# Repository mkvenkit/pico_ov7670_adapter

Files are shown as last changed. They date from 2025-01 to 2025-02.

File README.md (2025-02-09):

# pico_ov7670_adapter

An adapter PCB for using Pico 2W with an OV7670 camera module.

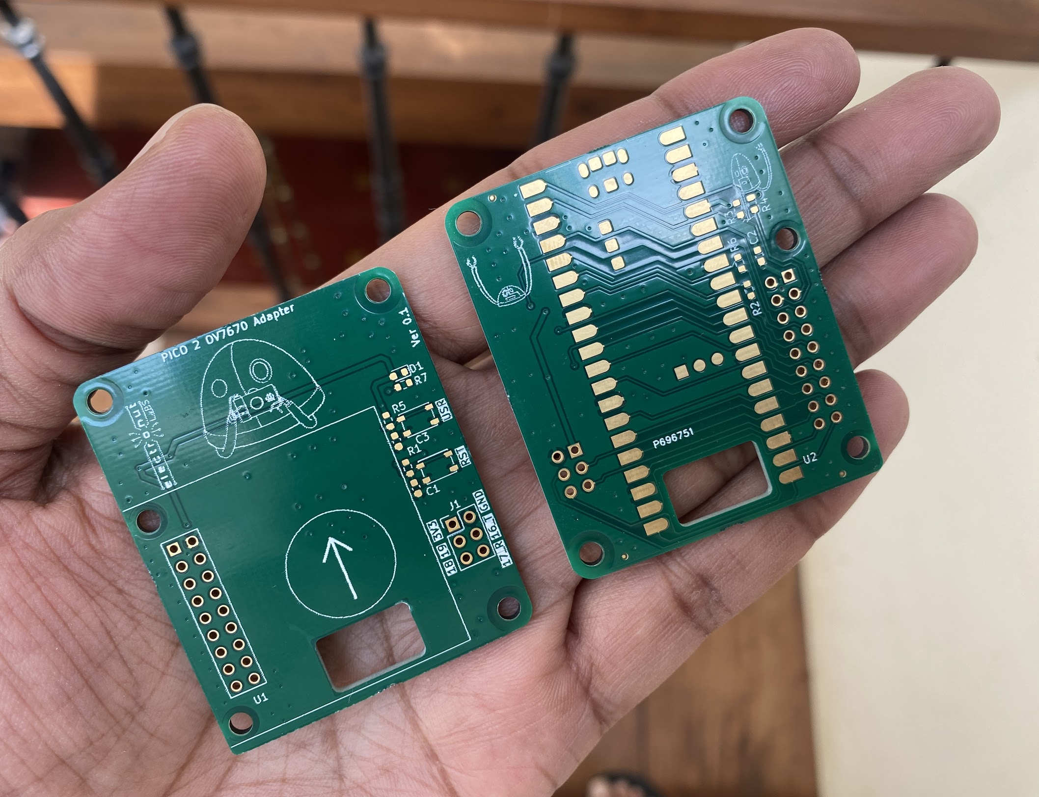
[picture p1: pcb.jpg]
pcb


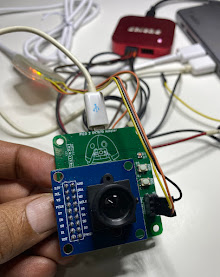
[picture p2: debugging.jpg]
debugging


# License

<p xmlns:cc="http://creativecommons.org/ns#" xmlns:dct="http://purl.org/dc/terms/"><a property="dct:title" rel="cc:attributionURL" href="http://electronut.in">Pico 2 OV7670 Adapter PCB</a> by <a rel="cc:attributionURL dct:creator" property="cc:attributionName" href="http://electronut.in">Mahesh Venkitachalam</a> is licensed under <a href="https://creativecommons.org/licenses/by/4.0/?ref=chooser-v1" target="_blank" rel="license noopener noreferrer" style="display:inline-block;">CC BY 4.0</a></p>

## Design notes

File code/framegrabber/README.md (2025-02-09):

# Frame Grabber for Pico 2 OV7670 Adapter

This is a frame grabber for capturing QVGA (320 x 420) RGB56 images and sending them over UART. The serial data is parsed by a Python program on the computer and a PNG RGB image created.

### UART Pins

```
UART_TX_PIN GP16
UART_RX_PIN GP17
```

## Current Status 

Output is garbled.

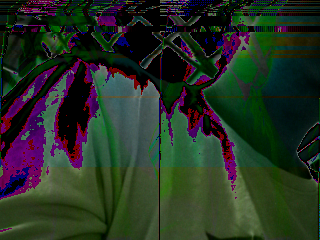
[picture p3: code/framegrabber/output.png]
output


Output with lenscap:

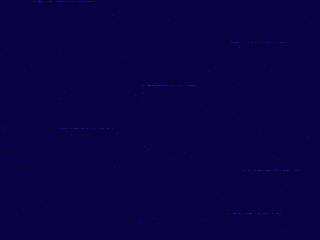
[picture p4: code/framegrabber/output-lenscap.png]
output with lenscap


## OV7670 Setup

The OV7670 registers are set to QVGA RGB565. I2C is verified to be working. Changing reg values is changing signal output.

### Signals from Logic Analyzer

The signals from OV7670 are consistent with QVGA (320 x 240) RGB565 - 2 PCLK pulses per pixel.

I am supplying XCLK at 15 MHz. Hence PCLK is at about 7.5 MHz.

**VSYNC**

Here's VSYNC. It's the same for VGA, QVGA, etc. Timing is correct.

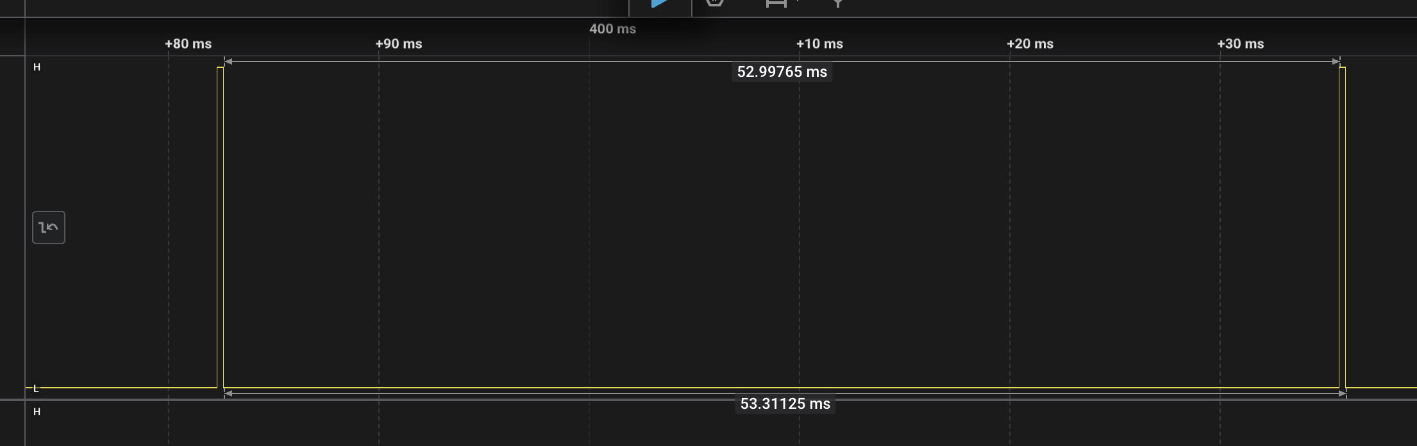
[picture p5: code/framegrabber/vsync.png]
vysnc


**HREF**

Here's HREF. 

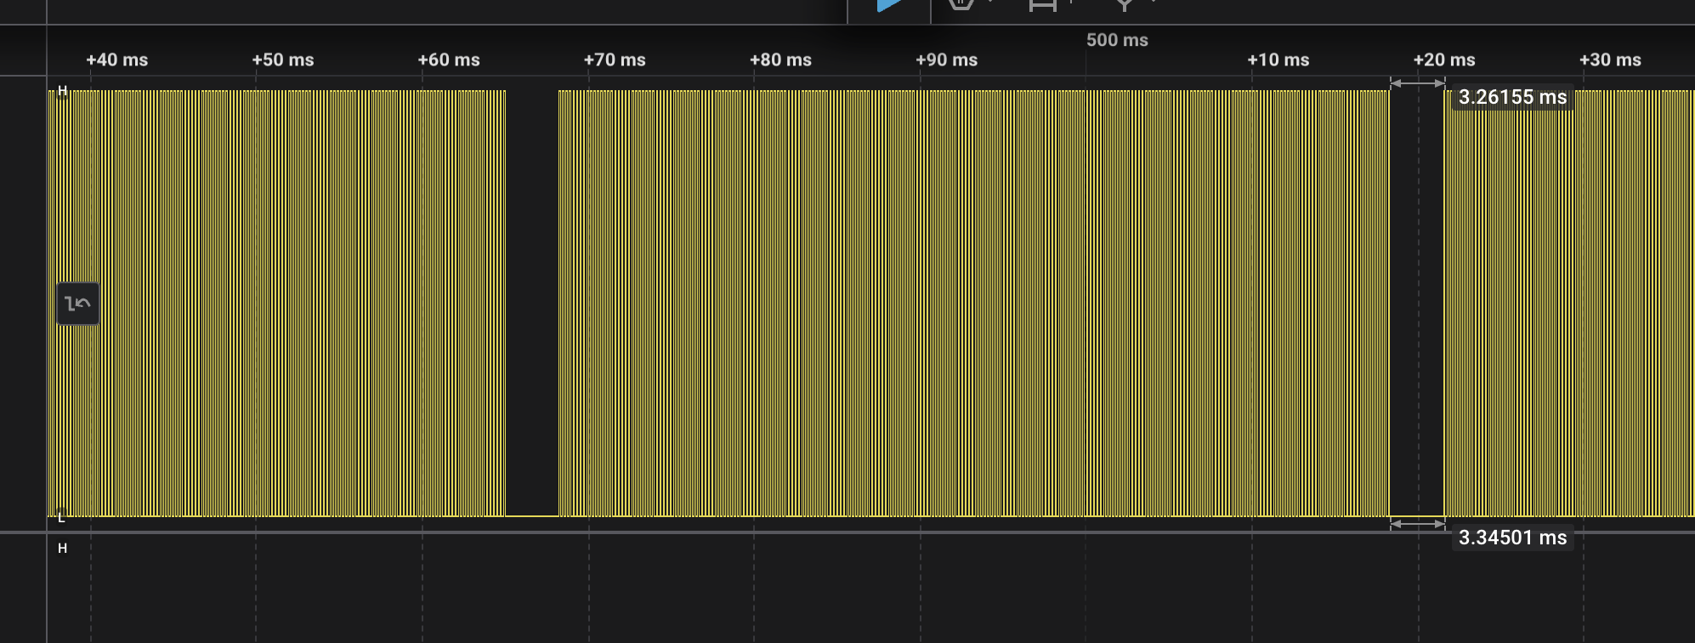
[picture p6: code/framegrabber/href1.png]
href1


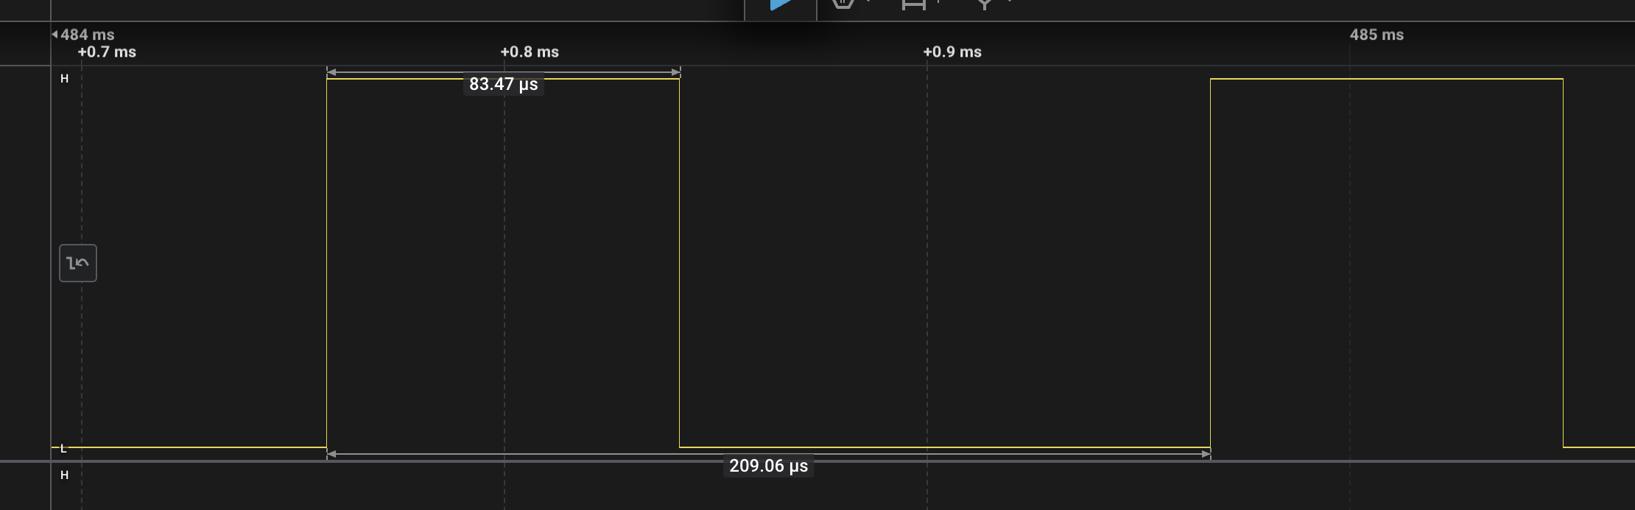
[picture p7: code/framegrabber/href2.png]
href2


From the above, 50.17 ms/(209.07 us) = 239.96 - ie, 240 is the number of rows, or height of the image. 

**PCLK**

Here's PCLK and HREF together.

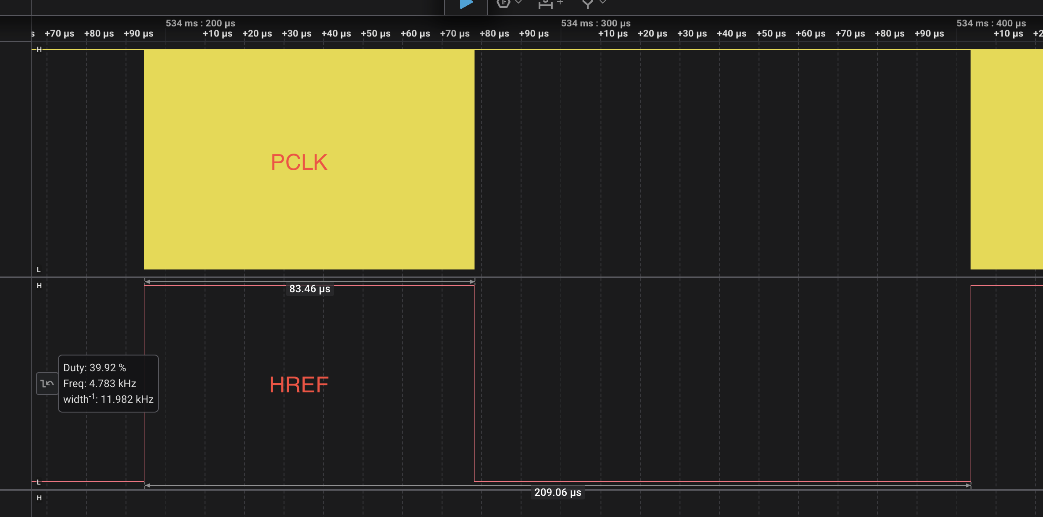
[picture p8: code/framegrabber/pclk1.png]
pclk1


Here's PCLK by itself.

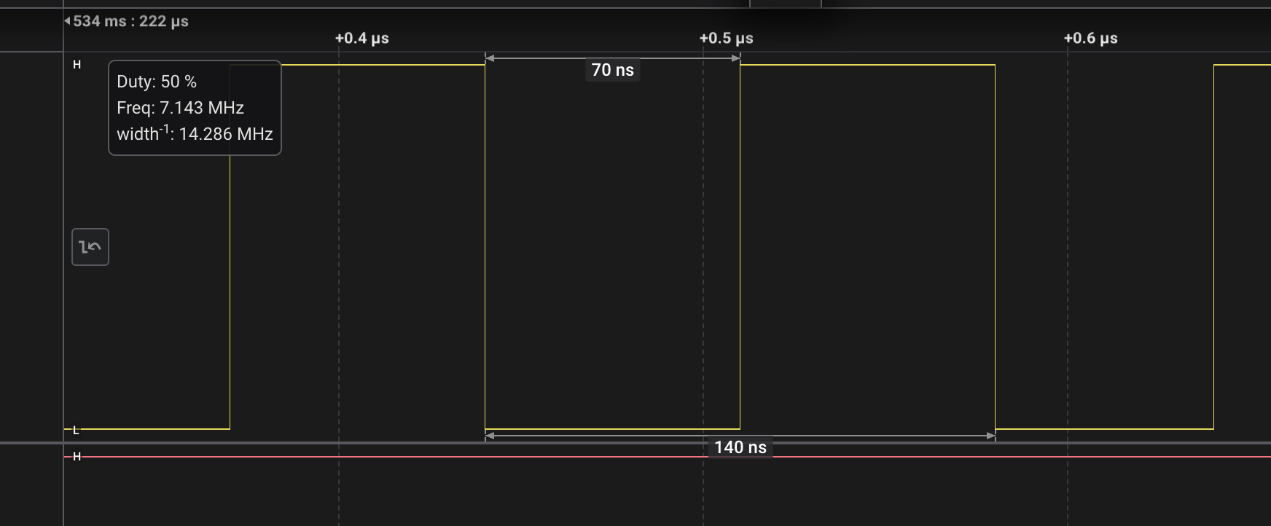
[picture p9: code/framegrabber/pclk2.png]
pclk2


From the above, 83.46 us/ 130 ns = 642. So 640 is the image width. At 2 x PCLKs per pixels, it's consistent with 2 * 320 = 640.

## Data Pins

On the PCBs, OV7670 D7..D0 are connected to GP6...GP13.

So,keeping GP6 as BASE pin in PIO, means that our data byte will be flipped in bits. This is corrected per byte before transmitting via UART.

## PIO

The PIO below does the following:

1. Read width (2 * 320 - 1 = 639) from TX FIFO.
2. Read OSR value into X register.
3. Wait for HREF to go high.
4. Wait for PCLK to go high.
5. Read in 8 pins GP6-GP13 to ISR. SM is set to auto-push from ISR to RX FIFO.
6. Loop till x-- is 0 (post-decr, hence N-1)

```
.program ov7670_qvga_565

    pull block    ; wait for width from OSR which comes from TX FIFO via auto-push
    wait 1 pin 2  ; Wait for VSYNC high (GP2 - Start of new frame)
    wait 0 pin 2  ; Wait for VSYNC low

.wrap_target
    mov x, OSR    ; move from OSR to X
    wait 1 pin 3  ; Wait for HREF high (GP3 - Row start)

pixel_loop:
    wait 1 pin 4  ; Wait for PCLK rising edge (GP4 - Pixel clock)
    in pins, 8    ; Read 8-bit pixel data from GP0-GP7
    wait 0 pin 4  ; Wait for PCLK falling edge
    jmp x-- pixel_loop  ; Continue while X not 0

    wait 0 pin 3  ; Wait for HREF low 
.wrap
```

## DMA 

The DMA is set up as follows:

1. 32 bit data transfer.
2. src is RX FIFO.
3. dst is uint8_t* buffer.
4. Data length is 2 * 320 * 240 / 4 bytes

I have tested the PIO + DMA by removing OV7670, setting D7-D0 using wires to the bit pattern 0xCB and it was received via UART on the PC correctly.

## Data Format

On PCLK, 8 bits GP6-GP13 are right-shifted into the 32-bit ISR, and after 4 PCLKs, ISR is auto-pushed to the RX FIFO which looks like:

```
|GP13...GP6|GP13...GP6|GP13...GP6|GP13...GP6|
```

This is copied by DMA to uint8_t* buffer and the write address incremented.

So the bytes end up in uint8_t* buffer as:

```
[0] GP13...GP6
[1] GP13...GP6
[2] GP13...GP6
[3] GP13...GP6
```

Before UART transmission, each byte is reversed - so we have:

```
[0] GP6...GP13
[1] GP6...GP13
[2] GP6...GP13
[3] GP6...GP13
```

Which is same as:

```
[0] D7...D0
[1] D7...D0
[2] D7...D0
[3] D7...D0
```

Which is correct. [0] and [1] are the RGB565 values for a pixel split across two bytes.

## Development Plan 

1. [+] Send a PWM to XCLK and check href, vsync, pclk signals.
2. [+] Hook up I2C and set output to 320 x 240 - check signals for correctness
3. [+] Write PIO code.
3. [+] Set up DMA to transfer to buffer.
4. [+] UART code to send buffer.
5. [+] Python code on PC to read from serial and display image data 

## Equivalent PIO of Sandeep's code

https://github.com/ArmDeveloperEcosystem/hm01b0-library-for-pico/blob/main/src/hm01b0.c#L149

```
.program camera_capture
    pull        block      ; Pull OSR value into PIO
    wait 0 pin vsync_pin  ; Wait for VSYNC to go low
    wait 1 pin vsync_pin  ; Wait for VSYNC to go high
    set y, num_border_px-1

border_y_loop:
    wait 1 pin hsync_pin  ; Wait for HSYNC to go high
    wait 0 pin hsync_pin  ; Wait for HSYNC to go low
    jmp  y--, border_y_loop

.wrap_target
    mov x, osr            ; Load OSR into X register
frame_loop:
    wait 1 pin hsync_pin  ; Wait for HSYNC to go high
    set y, num_border_px * num_pclk_per_px - 1

border_x_loop:
    wait 1 pin pclk_pin   ; Wait for PCLK to go high
    wait 0 pin pclk_pin   ; Wait for PCLK to go low
    jmp  y--, border_x_loop

pixel_loop:
    wait 1 pin pclk_pin   ; Wait for PCLK to go high
    in   pins, data_bits  ; Read pixel data
    wait 0 pin pclk_pin   ; Wait for PCLK to go low
    jmp  x--, pixel_loop  ; Loop for pixel read

    wait 0 pin hsync_pin  ; Wait for HSYNC to go low
.wrap
```

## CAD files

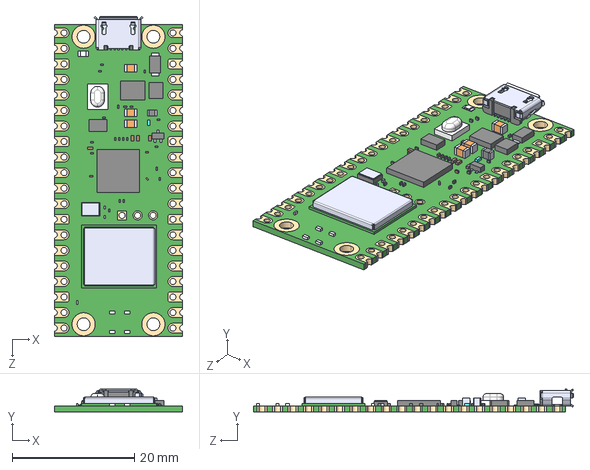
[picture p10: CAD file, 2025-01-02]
pcb/ver1.0/3d_model/RASPBERRY_PI_PICO_W.step
21.0 x 3.73 x 52.3 mm

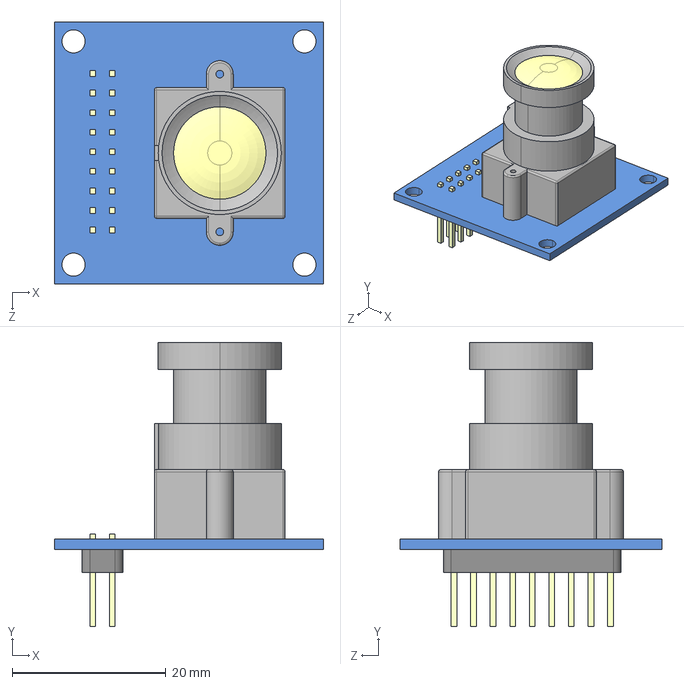
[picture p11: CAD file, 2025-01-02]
pcb/ver1.0/3d_model/OV7670_module.STEP
35.0 x 36.9 x 34.0 mm

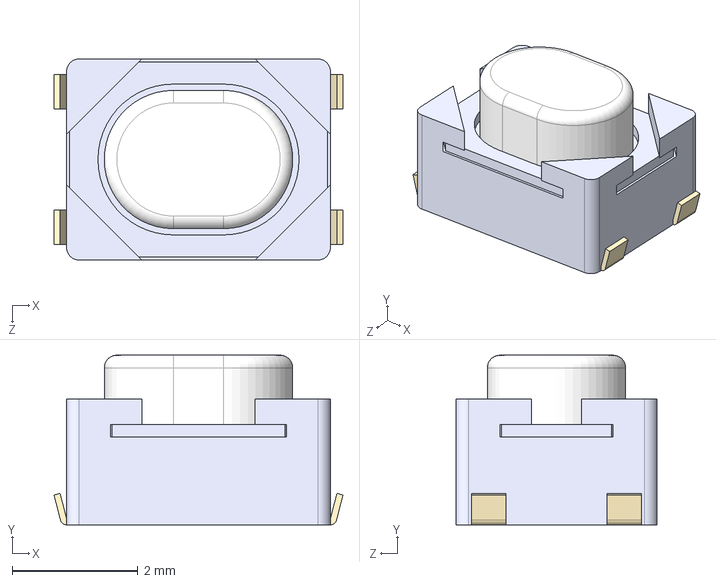
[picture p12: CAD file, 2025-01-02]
pcb/ver1.0/3d_model/PTS810SJK250SMTRLFS--3DModel-STEP-56544.STEP
4.60 x 2.70 x 3.20 mm

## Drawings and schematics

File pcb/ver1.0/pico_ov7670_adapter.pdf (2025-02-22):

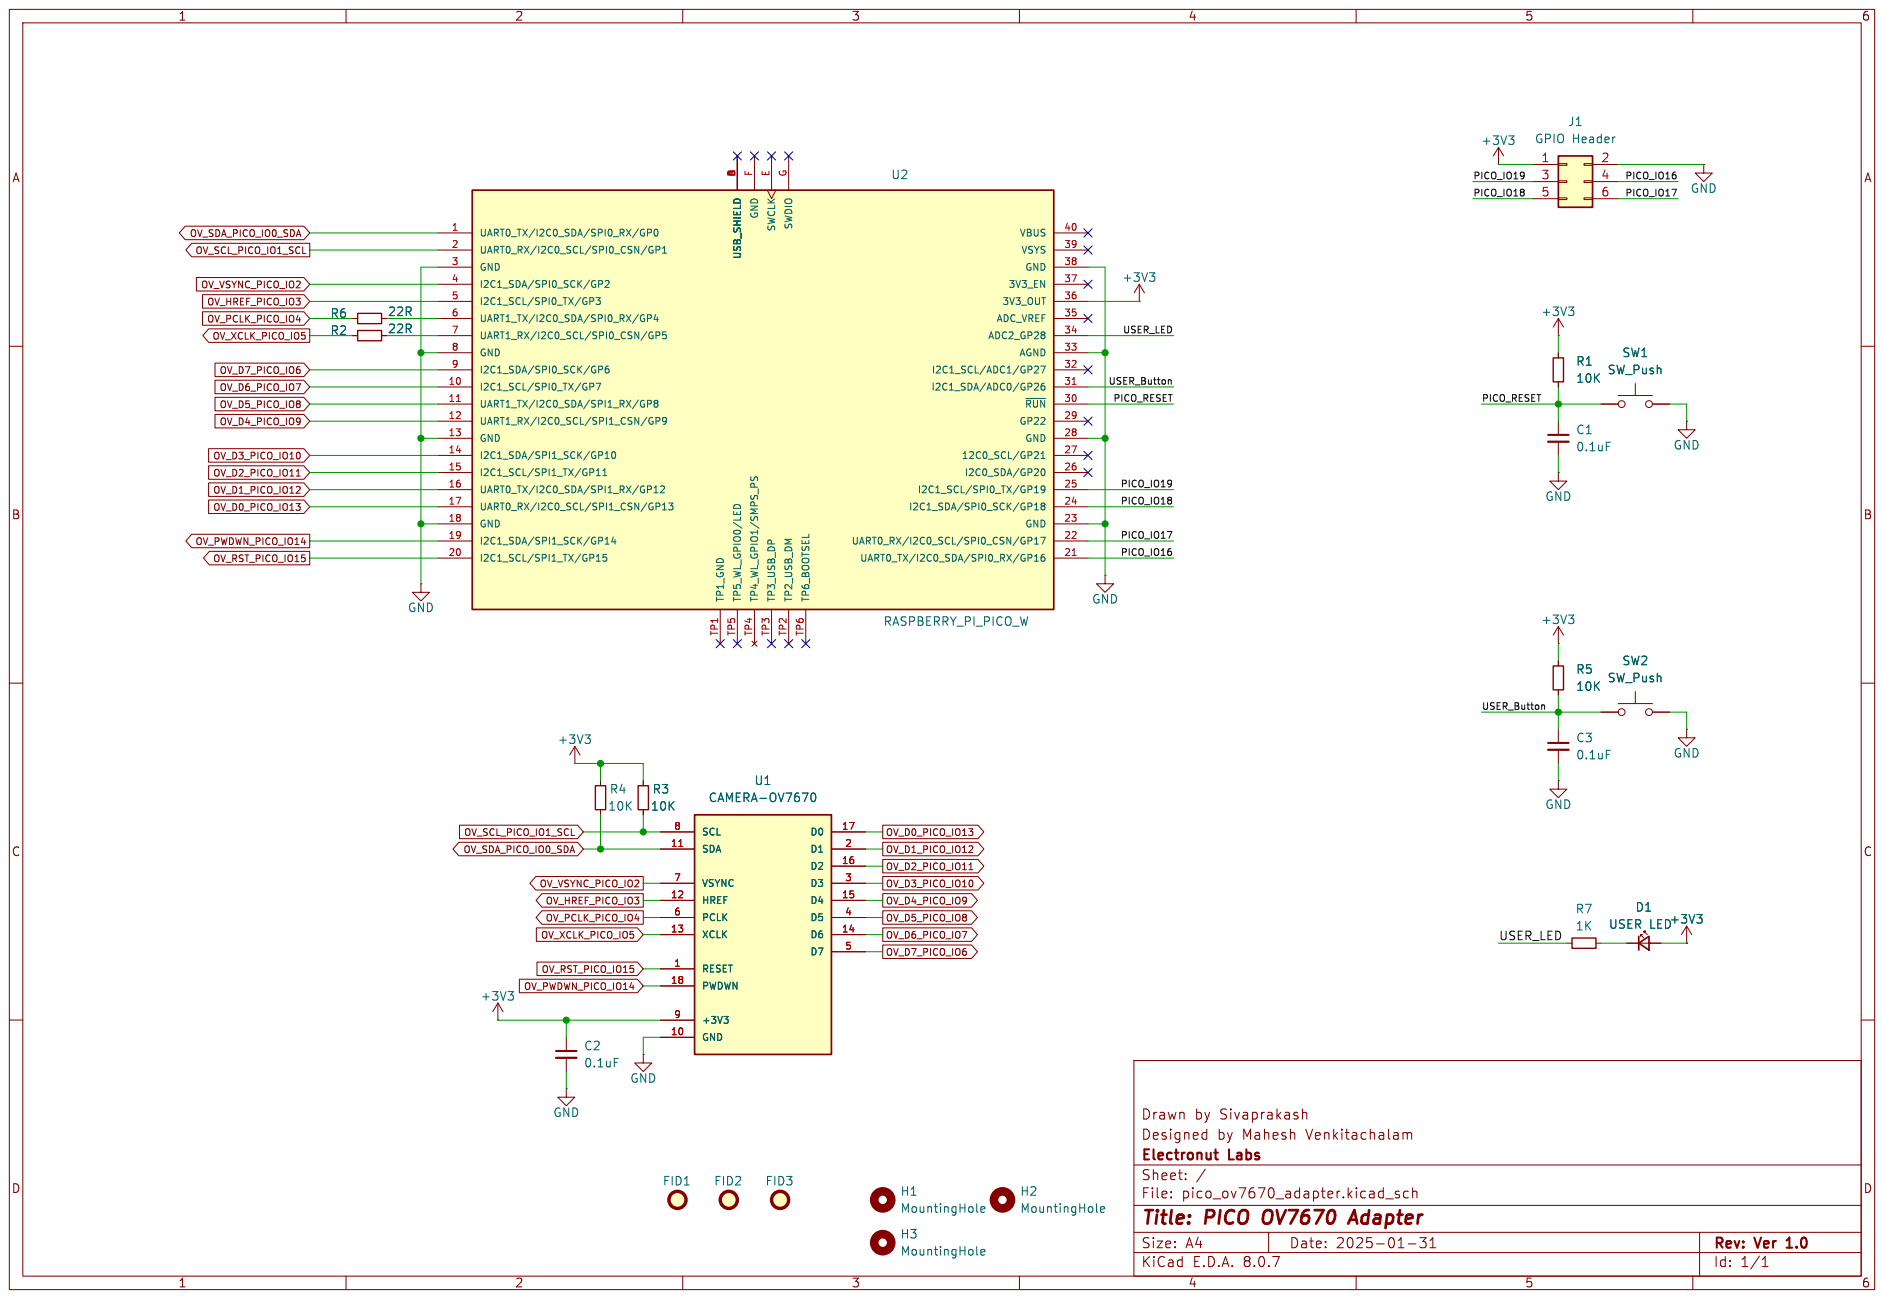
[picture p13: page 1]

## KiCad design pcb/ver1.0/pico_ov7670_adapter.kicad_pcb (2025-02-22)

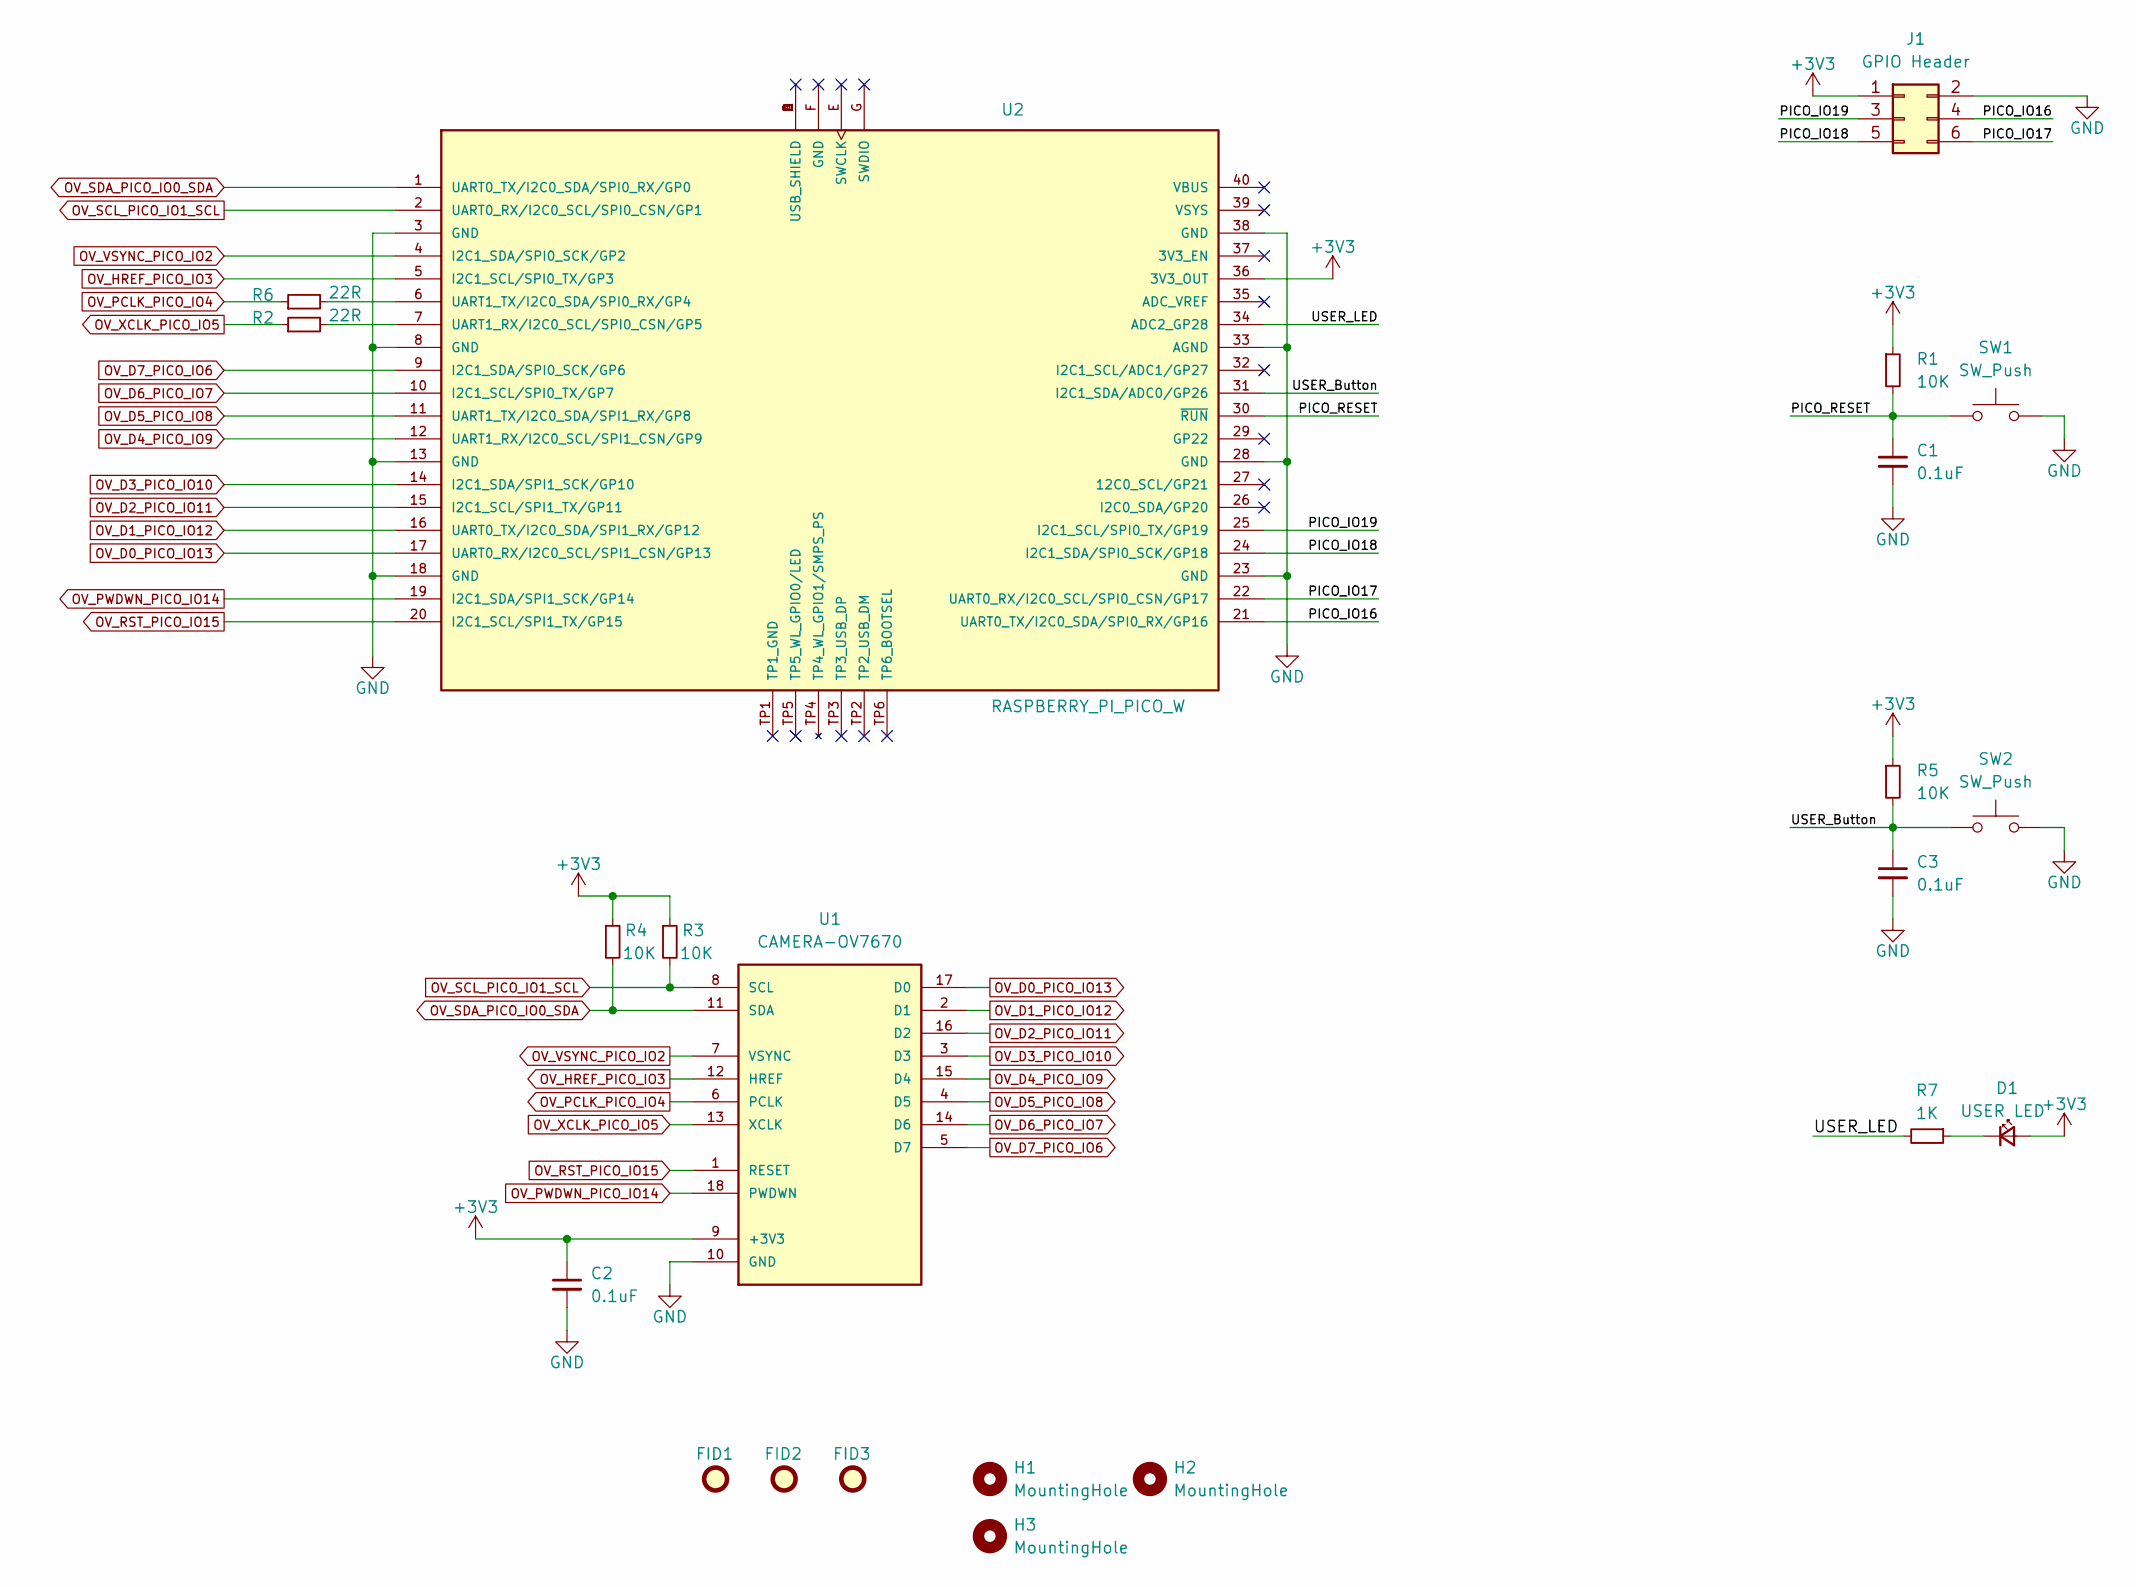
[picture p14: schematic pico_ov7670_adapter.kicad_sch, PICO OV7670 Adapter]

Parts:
C1, C2, C3: 0.1uF; C_0603_1608Metric
D1: USER LED; LED_0603_1608Metric
FID1, FID2, FID3: Fiducial; Fiducial_0.5mm_Mask1mm
H1, H2, H3: MountingHole; MountingHole_3.2mm_M3_DIN965
J1: GPIO Header; PinHeader_2x03_P2.54mm_Vertical
R1, R3, R4, R5: 10K; R_0603_1608Metric
R2, R6: 22R; R_0603_1608Metric
R7: 1K; R_0603_1608Metric
SW1, SW2: SW_Push; SW_SPST_PTS810
U1: CAMERA-OV7670; CAMERA-OV7670-DIP
U2: RASPBERRY_PI_PICO_W; PARTREV 2.4

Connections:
+3V3: C2.1, D1.2 (A), J1.1, R1.1, R3.1, R4.1, R5.1, U1.9 (+3V3), U2.36 (3V3_OUT)
/PICO_IO16: J1.4, U2.21 (UART0_TX/I2C0_SDA/SPI0_RX/GP16)
/PICO_IO17: J1.6, U2.22 (UART0_RX/I2C0_SCL/SPI0_CSN/GP17)
/PICO_IO18: J1.5, U2.24 (I2C1_SDA/SPI0_SCK/GP18)
/PICO_IO19: J1.3, U2.25 (I2C1_SCL/SPI0_TX/GP19)
/PICO_RESET: C1.1, R1.2, SW1.1, U2.30 (~RUN)
/USER_Button: C3.1, R5.2, SW2.1, U2.31 (I2C1_SDA/ADC0/GP26)
/USER_LED: R7.2, U2.34 (ADC2_GP28)
GND: C1.2, C2.2, C3.2, J1.2, SW1.2, SW2.2, U1.10 (GND), U2.3 (GND), U2.8 (GND), U2.13 (GND), U2.18 (GND), U2.23 (GND), U2.28 (GND), U2.33 (AGND), U2.38 (GND)
unnamed: D1.1 (K), R7.1
unnamed: R2.2, U2.7 (UART1_RX/I2C0_SCL/SPI0_CSN/GP5)
unnamed: R6.2, U2.6 (UART1_TX/I2C0_SDA/SPI0_RX/GP4)
OV_D0_PICO_IO13: U1.17 (D0), U2.17 (UART0_RX/I2C0_SCL/SPI1_CSN/GP13)
OV_D1_PICO_IO12: U1.2 (D1), U2.16 (UART0_TX/I2C0_SDA/SPI1_RX/GP12)
OV_D2_PICO_IO11: U1.16 (D2), U2.15 (I2C1_SCL/SPI1_TX/GP11)
OV_D3_PICO_IO10: U1.3 (D3), U2.14 (I2C1_SDA/SPI1_SCK/GP10)
OV_D4_PICO_IO9: U1.15 (D4), U2.12 (UART1_RX/I2C0_SCL/SPI1_CSN/GP9)
OV_D5_PICO_IO8: U1.4 (D5), U2.11 (UART1_TX/I2C0_SDA/SPI1_RX/GP8)
OV_D6_PICO_IO7: U1.14 (D6), U2.10 (I2C1_SCL/SPI0_TX/GP7)
OV_D7_PICO_IO6: U1.5 (D7), U2.9 (I2C1_SDA/SPI0_SCK/GP6)
OV_HREF_PICO_IO3: U1.12 (HREF), U2.5 (I2C1_SCL/SPI0_TX/GP3)
OV_PCLK_PICO_IO4: R6.1, U1.6 (PCLK)
OV_PWDWN_PICO_IO14: U1.18 (PWDWN), U2.19 (I2C1_SDA/SPI1_SCK/GP14)
OV_RST_PICO_IO15: U1.1 (RESET), U2.20 (I2C1_SCL/SPI1_TX/GP15)
OV_SCL_PICO_IO1_SCL: R3.2, U1.8 (SCL), U2.2 (UART0_RX/I2C0_SCL/SPI0_CSN/GP1)
OV_SDA_PICO_IO0_SDA: R4.2, U1.11 (SDA), U2.1 (UART0_TX/I2C0_SDA/SPI0_RX/GP0)
OV_VSYNC_PICO_IO2: U1.7 (VSYNC), U2.4 (I2C1_SDA/SPI0_SCK/GP2)
OV_XCLK_PICO_IO5: R2.1, U1.13 (XCLK)

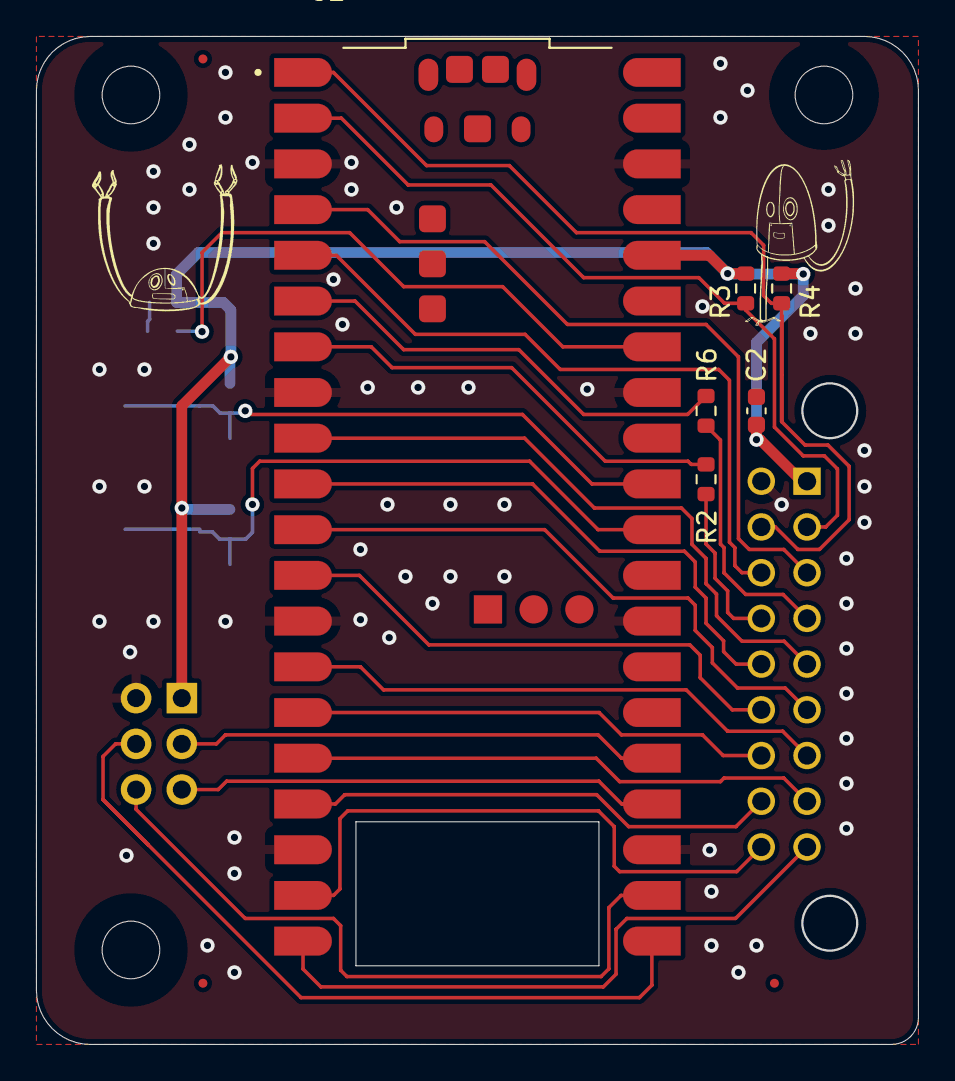
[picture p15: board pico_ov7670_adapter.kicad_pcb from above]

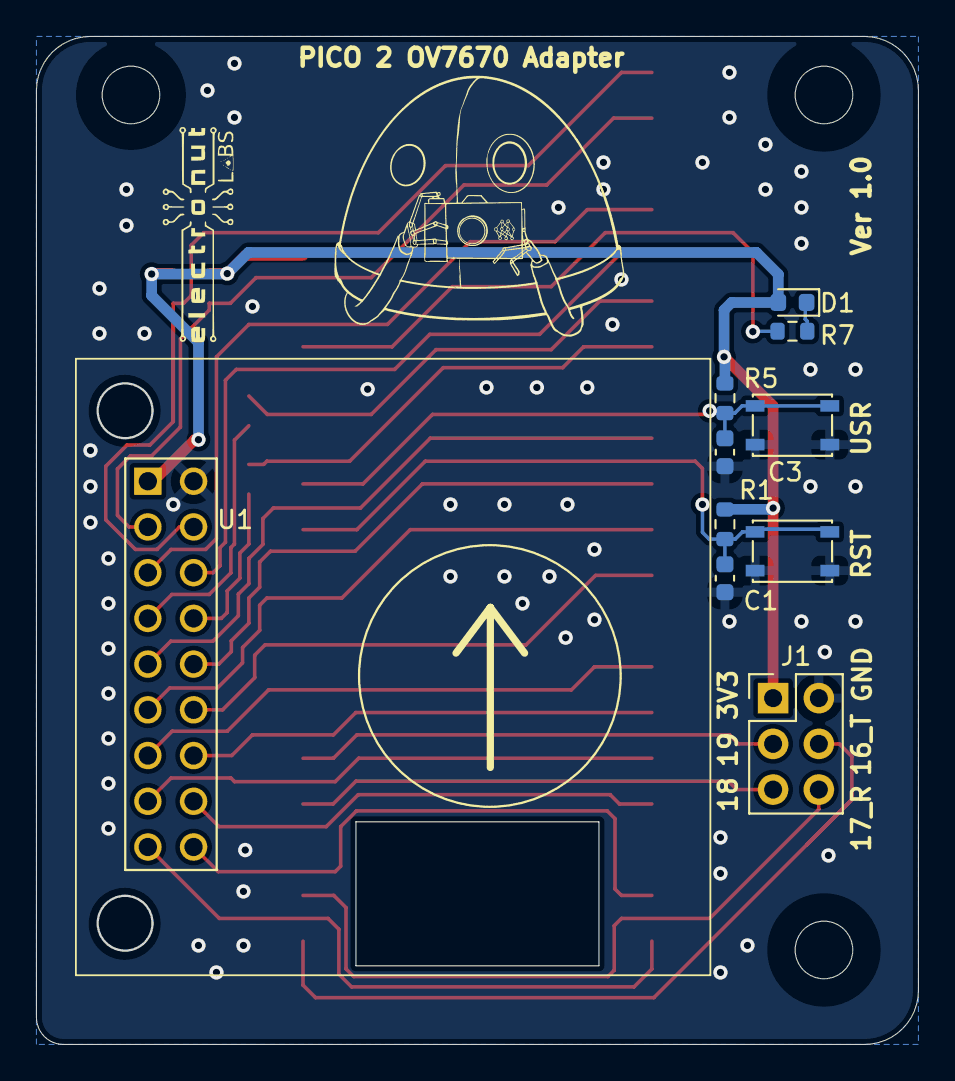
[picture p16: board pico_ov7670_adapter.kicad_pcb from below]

Board: 2 copper layers, 49.0 x 56.0 mm, 22 parts (10 on the bottom side), 28 nets.

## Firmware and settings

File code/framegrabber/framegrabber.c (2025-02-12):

#include <stdio.h>
#include "pico/stdlib.h"
#include "hardware/dma.h"
#include "hardware/pwm.h"
#include "hardware/pio.h"
#include "hardware/i2c.h"
#include "pico/cyw43_arch.h"
#include "hardware/uart.h"
#include "hardware/clocks.h"

#include "hardware/regs/io_bank0.h"
#include "hardware/regs/sio.h"
#include "hardware/structs/sio.h"

#include "OV7670.h"

// UART defines
// By default the stdout UART is `uart0`, so we will use the second one
#define UART_ID uart1
#define BAUD_RATE 115200

// Use pins 4 and 5 for UART1
// Pins can be changed, see the GPIO function select table in the datasheet for information on GPIO assignments
#define UART_TX_PIN 16
#define UART_RX_PIN 17

#define IMAGE_WIDTH  320
#define IMAGE_HEIGHT 240
#define IMAGE_SIZE   (IMAGE_WIDTH * IMAGE_HEIGHT)  // Total bytes

// QVGA image buffer - RGB565 requires 2 bytes per pixel
uint8_t image_buffer[IMAGE_SIZE * 2];

// for button press
volatile bool button_pressed = false;
volatile uint32_t last_press_time = 0;
volatile bool capturing_frame = false;  
#define BUTTON_PIN 26
#define DEBOUNCE_DELAY_MS 50
#define LED_PIN 28

// For testing RGB565 
static void create_test_image(uint8_t* buffer) {
    for (int y = 0; y < IMAGE_HEIGHT; y++) {
        for (int x = 0; x < IMAGE_WIDTH; x++) {
            uint16_t color;

            if (y < 80) {
                color = 0xF800;  // Red (RGB565)
            } else if (y < 160) {
                color = 0x07E0;  // Green (RGB565)
            } else {
                color = 0x001F;  // Blue (RGB565)
            }

            int index = (y * IMAGE_WIDTH + x) * 2;
            buffer[index] = color & 0xFF;         // Low byte
            buffer[index + 1] = (color >> 8) & 0xFF; // High byte
        }
    }
}

// D0-D7 is connected to GP13-GP6 - so need to reverse bits for each byte
static uint8_t reverse_bits(uint8_t byte) {
    byte = ((byte & 0xF0) >> 4) | ((byte & 0x0F) << 4);
    byte = ((byte & 0xCC) >> 2) | ((byte & 0x33) << 2);
    byte = ((byte & 0xAA) >> 1) | ((byte & 0x55) << 1);
    return byte;
}

// send image over UART
static void send_image(uart_inst_t* uart, uint8_t* buffer) {
    for (int i = 0; i < IMAGE_SIZE * 2; i++) {  // Send all pixels (each pixel = 2 bytes)
        //uart_putc(uart, buffer[i]);
        uint8_t val = reverse_bits(buffer[i]);
        printf("%c", val);
    }
}

// Interrupt Handler for Button Press
void button_callback(uint gpio, uint32_t events) {
    uint32_t current_time = to_ms_since_boot(get_absolute_time());

    // Ignore if a frame is currently being captured
    if (capturing_frame) return;

    // Debounce check
    if (current_time - last_press_time < DEBOUNCE_DELAY_MS) return;

    last_press_time = current_time;
    button_pressed = true;  // Mark that button was pressed
}

// OV7670 camera pins (Pico 2W)
#define PCLK_PIN   4  // Pixel clock (INPUT)
#define VSYNC_PIN  2  // Frame sync (INPUT)
#define HREF_PIN   3  // Row sync (INPUT)
#define DATA_BASE  6  // GP6-GP13 (8-bit parallel data INPUT)

// Data pins (D0-D7 mapped to GP6-GP13)
#define DATA_PIN_BASE 6  // First data pin (D0 -> GP6)
#define DATA_MASK (0xFF << DATA_PIN_BASE)  // Mask for GPIO6-GPIO13

void grab_frame()
{
    // Initialize control pins as INPUT
    gpio_init(PCLK_PIN);
    gpio_set_dir(PCLK_PIN, GPIO_IN);
    gpio_init(VSYNC_PIN);
    gpio_set_dir(VSYNC_PIN, GPIO_IN);
    gpio_init(HREF_PIN);
    gpio_set_dir(HREF_PIN, GPIO_IN);

    // Initialize data pins as INPUT
    for (int pin = DATA_BASE; pin < DATA_BASE + 8; pin++) {
        gpio_init(pin);
        gpio_set_dir(pin, GPIO_IN);
    }

    uint16_t y, x;
    uint8_t *bufPtr = image_buffer;

    // Wait for VSYNC to go HIGH then LOW (Frame start)
    while (!(gpio_get(VSYNC_PIN)));  // Wait for HIGH
    while (gpio_get(VSYNC_PIN));     // Wait for LOW (Frame start)

    y = 240;
    while (y--) {
        x = 640;
        while (x--) {
            // Wait for PCLK to go LOW
            while (gpio_get(PCLK_PIN));

            // Read 8-bit parallel data in one operation
            //uint32_t gpio_value = gpio_get_all();
            //uint8_t byteData = (gpio_value & DATA_MASK) >> DATA_PIN_BASE;

            // Read 8-bit parallel data in one operation using direct register access
            uint8_t byteData = (sio_hw->gpio_in & DATA_MASK) >> DATA_PIN_BASE;


            // Store the byte in the buffer
            *bufPtr++ = byteData;

            // Wait for PCLK to go HIGH
            while (!gpio_get(PCLK_PIN));
        }
    }
}

void capture_frame()
{
    // turn LED on 
    gpio_put(LED_PIN, 0); // on

    // grab frame
    ov7670_grab_frame();

    //grab_frame();

    // send over uart 
    send_image(UART_ID, image_buffer);

    // LED off 
    gpio_put(LED_PIN, 1); // off 
}

int main()
{
    stdio_init_all();    
    // Set up our UART
    uart_init(UART_ID, BAUD_RATE);
    // Set the TX and RX pins by using the function select on the GPIO
    // Set datasheet for more information on function select
    gpio_set_function(UART_TX_PIN, GPIO_FUNC_UART);
    gpio_set_function(UART_RX_PIN, GPIO_FUNC_UART);

    // Init I2C pins
    gpio_set_function(0, GPIO_FUNC_I2C);
    gpio_set_function(1, GPIO_FUNC_I2C);
    gpio_pull_up(0);
    gpio_pull_up(1);

    // Init LED pin 
    gpio_init(LED_PIN);       
    gpio_set_dir(LED_PIN, GPIO_OUT);  
    gpio_put(LED_PIN, 1); // off 

    // Configure button pin as input with pull-up
    gpio_init(BUTTON_PIN);
    gpio_set_dir(BUTTON_PIN, GPIO_IN);
    gpio_pull_up(BUTTON_PIN);  // External pull-up exists, but safe to enable

    // Attach interrupt on falling edge (button press)
    gpio_set_irq_enabled_with_callback(BUTTON_PIN, GPIO_IRQ_EDGE_FALL, true, &button_callback);

    // init OV7670
    ov7670_init(image_buffer);

    sleep_ms(1000);
    capture_frame();

    //  main loop 
    while (true) {
        if (button_pressed) {
            button_pressed = false;  // Reset flag
            capturing_frame = true;  // Mark as busy

            capture_frame();

            capturing_frame = false;  // Mark as ready for next press
            
        }
        sleep_ms(100);
    }
}

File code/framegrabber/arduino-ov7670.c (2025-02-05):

////////////////////////////////////////////////////////////////////////////////
////  Author : Pintu shaw //////////////////////////////////////////////////////
////  Date: 11 MAY 2019   //////////////////////////////////////////////////////
////////////////////////////////////////////////////////////////////////////////
#include <stdint.h>
#include <avr/io.h>
#include <util/twi.h>
#include <util/delay.h>
#include <avr/pgmspace.h>

#define F_CPU 16000000UL
#define vga   0
#define qvga  1 
#define qqvga   2
#define yuv422  0
#define rgb565  1
#define bayerRGB  2
#define camAddr_WR  0x42
#define camAddr_RD  0x43

/* Registers */
#define REG_GAIN    0x00  /* Gain lower 8 bits (rest in vref) */
#define REG_BLUE    0x01  /* blue gain */
#define REG_RED       0x02  /* red gain */
#define REG_VREF    0x03  /* Pieces of GAIN, VSTART, VSTOP */
#define REG_COM1    0x04  /* Control 1 */
#define COM1_CCIR656  0x40    /* CCIR656 enable */

#define REG_BAVE    0x05  /* U/B Average level */
#define REG_GbAVE   0x06  /* Y/Gb Average level */
#define REG_AECHH   0x07  /* AEC MS 5 bits */
#define REG_RAVE    0x08  /* V/R Average level */
#define REG_COM2    0x09  /* Control 2 */
#define COM2_SSLEEP         0x10  /* Soft sleep mode */
#define REG_PID           0x0a  /* Product ID MSB */
#define REG_VER           0x0b  /* Product ID LSB */
#define REG_COM3    0x0c  /* Control 3 */
#define COM3_SWAP         0x40  /* Byte swap */
#define COM3_SCALEEN          0x08  /* Enable scaling */
#define COM3_DCWEN          0x04  /* Enable downsamp/crop/window */
#define REG_COM4    0x0d  /* Control 4 */
#define REG_COM5    0x0e  /* All "reserved" */
#define REG_COM6    0x0f  /* Control 6 */
#define REG_AECH    0x10  /* More bits of AEC value */
#define REG_CLKRC   0x11  /* Clocl control */
#define CLK_EXT           0x40  /* Use external clock directly */
#define CLK_SCALE   0x3f  /* Mask for internal clock scale */
#define REG_COM7    0x12  /* Control 7 */ //REG mean address.
#define COM7_RESET          0x80  /* Register reset */
#define COM7_FMT_MASK         0x38
#define COM7_FMT_VGA          0x00
#define COM7_FMT_CIF          0x20  /* CIF format */
#define COM7_FMT_QVGA         0x10  /* QVGA format */
#define COM7_FMT_QCIF         0x08  /* QCIF format */
#define COM7_RGB          0x04  /* bits 0 and 2 - RGB format */
#define COM7_YUV          0x00  /* YUV */
#define COM7_BAYER          0x01  /* Bayer format */
#define COM7_PBAYER         0x05  /* "Processed bayer" */
#define REG_COM8    0x13  /* Control 8 */
#define COM8_FASTAEC          0x80  /* Enable fast AGC/AEC */
#define COM8_AECSTEP          0x40  /* Unlimited AEC step size */
#define COM8_BFILT    0x20  /* Band filter enable */
#define COM8_AGC    0x04  /* Auto gain enable */
#define COM8_AWB    0x02  /* White balance enable */
#define COM8_AEC    0x01  /* Auto exposure enable */
#define REG_COM9    0x14  /* Control 9- gain ceiling */
#define REG_COM10   0x15  /* Control 10 */
#define COM10_HSYNC         0x40  /* HSYNC instead of HREF */
#define COM10_PCLK_HB         0x20  /* Suppress PCLK on horiz blank */
#define COM10_HREF_REV          0x08  /* Reverse HREF */
#define COM10_VS_LEAD         0x04  /* VSYNC on clock leading edge */
#define COM10_VS_NEG          0x02  /* VSYNC negative */
#define COM10_HS_NEG          0x01  /* HSYNC negative */
#define REG_HSTART    0x17  /* Horiz start high bits */
#define REG_HSTOP   0x18  /* Horiz stop high bits */
#define REG_VSTART    0x19  /* Vert start high bits */
#define REG_VSTOP   0x1a  /* Vert stop high bits */
#define REG_PSHFT   0x1b  /* Pixel delay after HREF */
#define REG_MIDH    0x1c  /* Manuf. ID high */
#define REG_MIDL    0x1d  /* Manuf. ID low */
#define REG_MVFP    0x1e  /* Mirror / vflip */
#define MVFP_MIRROR         0x20  /* Mirror image */
#define MVFP_FLIP   0x10  /* Vertical flip */
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

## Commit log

2025-01-02 basic schematic and layout updated
    [OV7670_module.STEP, PTS810SJK250SMTRLFS--3DModel-STEP-56544.STEP, RASPBERRY_PI_PICO_W.step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]
2025-01-05 footprints updated
    [pico_ov7670_adapter.kicad_pcb, pico_ov7670_adapter.kicad_sch]
2025-01-05 layout updated
    [pico_ov7670_adapter.kicad_pcb, pico_ov7670_adapter.kicad_sch]
2025-01-06 basic routing completed
    [pico_ov7670_adapter.kicad_pcb, pico_ov7670_adapter.kicad_sch]
2025-01-07 routing completed
    [pico_ov7670_adapter.kicad_pcb]
2025-01-09 art work updated in PCB
    [pico_ov7670_adapter-B_Cu.gbl, pico_ov7670_adapter-B_Mask.gbs, pico_ov7670_adapter-B_Paste.gbp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]
2025-01-11 via stitching added
    [pico_ov7670_adapter-B_Cu.gbl, pico_ov7670_adapter-B_Mask.gbs, pico_ov7670_adapter-B_Paste.gbp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]
2025-01-12 updated layout changes as per the feedback.
    [pico_ov7670_adapter.kicad_pcb, pico_ov7670_adapter.kicad_sch]
2025-01-14 layout updated.
    [pico_ov7670_adapter.kicad_pcb, pico_ov7670_adapter.kicad_sch]
2025-01-17 layout updated as per the feedback.
    [pico_ov7670_adapter.kicad_pcb, pico_ov7670_adapter.kicad_sch]
2025-01-18 basic rotuing completed
    [pico_ov7670_adapter.kicad_pcb, pico_ov7670_adapter.kicad_sch]
2025-01-18 GPIO header change updated
    [pico_ov7670_adapter.kicad_pcb, pico_ov7670_adapter.kicad_sch]
2025-01-18 gerber files added
    [pico_ov7670_adapter-B_Cu.gbl, pico_ov7670_adapter-B_Mask.gbs, pico_ov7670_adapter-B_Paste.gbp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]
2025-01-28 schematic pdf updated
    [pico_ov7670_adapter.kicad_sch]
2025-01-29 adding framegrabber
2025-01-29 I2C detected camera!
2025-01-30 I2c write works, QVGA configured
2025-01-30 height is correct QVGA 240 px
    [OV7670.c]
2025-02-02 sending image over uart
2025-02-03 Generated code for test image and PIO/DMA
2025-02-03 Added button and LED
2025-02-03 Hooking up DMA + PIO
2025-02-03 dma tested
2025-02-05 added linux driver code
2025-02-06 PWM peripheral works
2025-02-11 ver1.0 started
    [OV7670_module.STEP, PTS810SJK250SMTRLFS--3DModel-STEP-56544.STEP, RASPBERRY_PI_PICO_W.step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]
2025-02-12 wait syntax wrong
    wait 1 gpio 4 works!
    [OV7670.c, framegrabber.c]
2025-02-20 camera module footptint updated.
    [pico_ov7670_adapter-B_Cu.gbl, pico_ov7670_adapter-B_Mask.gbs, pico_ov7670_adapter-B_Paste.gbp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]
2025-02-20 removed old gerber files
    [pico_ov7670_adapter-B_Cu.gbl, pico_ov7670_adapter-B_Mask.gbs, pico_ov7670_adapter-B_Paste.gbp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]
